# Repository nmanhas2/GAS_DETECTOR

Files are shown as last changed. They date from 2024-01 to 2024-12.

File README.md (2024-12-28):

# GAS_DETECTOR
Gas Detection project I made while attending NAIT

This includes the PCB and circuit design I made using KiCad EDA. 

Here's how it works:

-Using a gas sensor to detect smoke/gas in PPM (parts per million, standard for measuring the volume of a gas)

-Once the sensor detects a certain amount of gas (displayed on an I2C supported LCD), an “alarm” activates (piezo buzzer). The volume of gas is not accurate I believe, as I had problems with determining the calculations

-The LCD will display the current volume of gas detected by the gas sensor in PPM

-Push button for Reset

Involves the following components:

-MQ-2 gas sensor, widely used with lots of resources/examples to look at, works at 5V (https://components101.com/sensors/mq2-gas-sensor) https://media.digikey.com/pdf/Data%20Sheets/Seeed%20Technology/101020055_Web.pdf

-LCD w/ I2C: AMC0802BR-B-Y6WFDY-I2C (https://www.digikey.ca/en/products/detail/orient-display/AMC0802BR-B-Y6WFDY-I2C/12089323), cheap on digikey, runs at 5V as well. 0111110 = I2C address 

-BH9VPC 9V battery holder (had this on hand) + LM7805 linear voltage regulator to get the 5V needed for everything

-ATmega328P for the microcontroller https://ww1.microchip.com/downloads/en/DeviceDoc/Atmel-7810-Automotive-Microcontrollers-ATmega328P_Datasheet.pdf

-Piezo Buzzer for the alarm (PS1240P02BT) https://www.digikey.ca/en/products/detail/tdk-corporation/PS1240P02BT/935924, can run on 3V minimum up to a maximum of 30Vp

-A push button

Here is the circuit schematic (may be difficult to see):



Here is the PCB design:





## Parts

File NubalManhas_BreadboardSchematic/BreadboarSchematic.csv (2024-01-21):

Source: | C:\Users\manha\OneDrive\Desktop\BreadboarSchematic\BreadboarSchematic.kicad_sch
Date: | 10/18/2022 11:07
Tool: | Eeschema (6.0.7)
Generator: | C:\Program Files\KiCad\6.0\bin\scripting\plugins/bom_csv_grouped_by_value_with_fp.py
Component Count: | 19
Ref | Qnty | Value | Cmp name | Footprint | Description | Vendor
BT1, | 1 | BH9VPC | BH9VPC | MyLib:BAT_BH9VPC
C1, C2, | 2 | 100uF | C_Polarized | Capacitor_SMD:CP_Elec_6.3x5.8 | Polarized capacitor
C3, C4, | 2 | 18pF | C | Capacitor_SMD:C_1206_3216Metric | Unpolarized capacitor
J1, | 1 | AVR-ISP-MK2 | Conn_02x05_Odd_Even | Connector_PinSocket_2.54mm:PinSocket_2x05_P2.54mm_Vertical | Generic connector, double row, 02x05, odd/even pin numbering scheme (row 1 odd numbers, row 2 even numbers), script generated (kicad-library-utils/schlib/autogen/connector/)
J2, | 1 | SKU 101020055 | Conn_01x04 | Connector_PinHeader_2.54mm:PinHeader_1x04_P2.54mm_Vertical | Generic connector, single row, 01x04, script generated (kicad-library-utils/schlib/autogen/connector/)
J3, | 1 | AMC0802BR-B-Y6WFDY-I2C | Conn_02x05_Odd_Even | Connector_PinHeader_2.54mm:PinHeader_2x05_P2.54mm_Vertical | Generic connector, double row, 02x05, odd/even pin numbering scheme (row 1 odd numbers, row 2 even numbers), script generated (kicad-library-utils/schlib/autogen/connector/)
LS1, | 1 | PS1240P02BT | PS1240P02BT | MyLib:XDCR_PS1240P02BT
Q1, | 1 | MMBT3904 | MMBT3904 | Package_TO_SOT_SMD:SOT-23 | 0.2A Ic, 40V Vce, Small Signal NPN Transistor, SOT-23
R1, | 1 | 10k | R_US | Resistor_SMD:R_1206_3216Metric | Resistor, US symbol
R2, | 1 | 1k | R_US | Resistor_SMD:R_1206_3216Metric | Resistor, US symbol
R3, | 1 | 82k | R_US | Resistor_SMD:R_1206_3216Metric | Resistor, US symbol
R4, R5, | 2 | 4.7k | R_US | Resistor_SMD:R_1206_3216Metric | Resistor, US symbol
RV1, | 1 | 10k | R_Potentiometer | Potentiometer_THT:Potentiometer_Bourns_3296W_Vertical | Potentiometer
U1, | 1 | LM7805_TO220 | LM7805_TO220 | Package_TO_SOT_THT:TO-220-3_Vertical | Positive 1A 35V Linear Regulator, Fixed Output 5V, TO-220
U2, | 1 | ATmega328P-P | ATmega328PB-A | Package_QFP:TQFP-32_7x7mm_P0.8mm | 20MHz, 32kB Flash, 2kB SRAM, 1kB EEPROM, TQFP-32
Y1, | 1 | HC49-4H 16MHz | Crystal | Crystal:Crystal_SMD_ECS_CSM3X-2Pin_7.6x4.1mm | Two pin crystal
 | 4 | M3x15+6mm Nylon Hex Male to Female Standoff
 | 4 | M3x15mm Double Female Standoff
SW1, | 1 | 108-0047-evx | SW_SPST | SamacSys_Parts:1080047EVX | Single Pole Single Throw (SPST) switch
D1, | 1 | /SML-LX1206SRW-TR | LED | BH9VPC:RESC3015X65 | Light emitting diode

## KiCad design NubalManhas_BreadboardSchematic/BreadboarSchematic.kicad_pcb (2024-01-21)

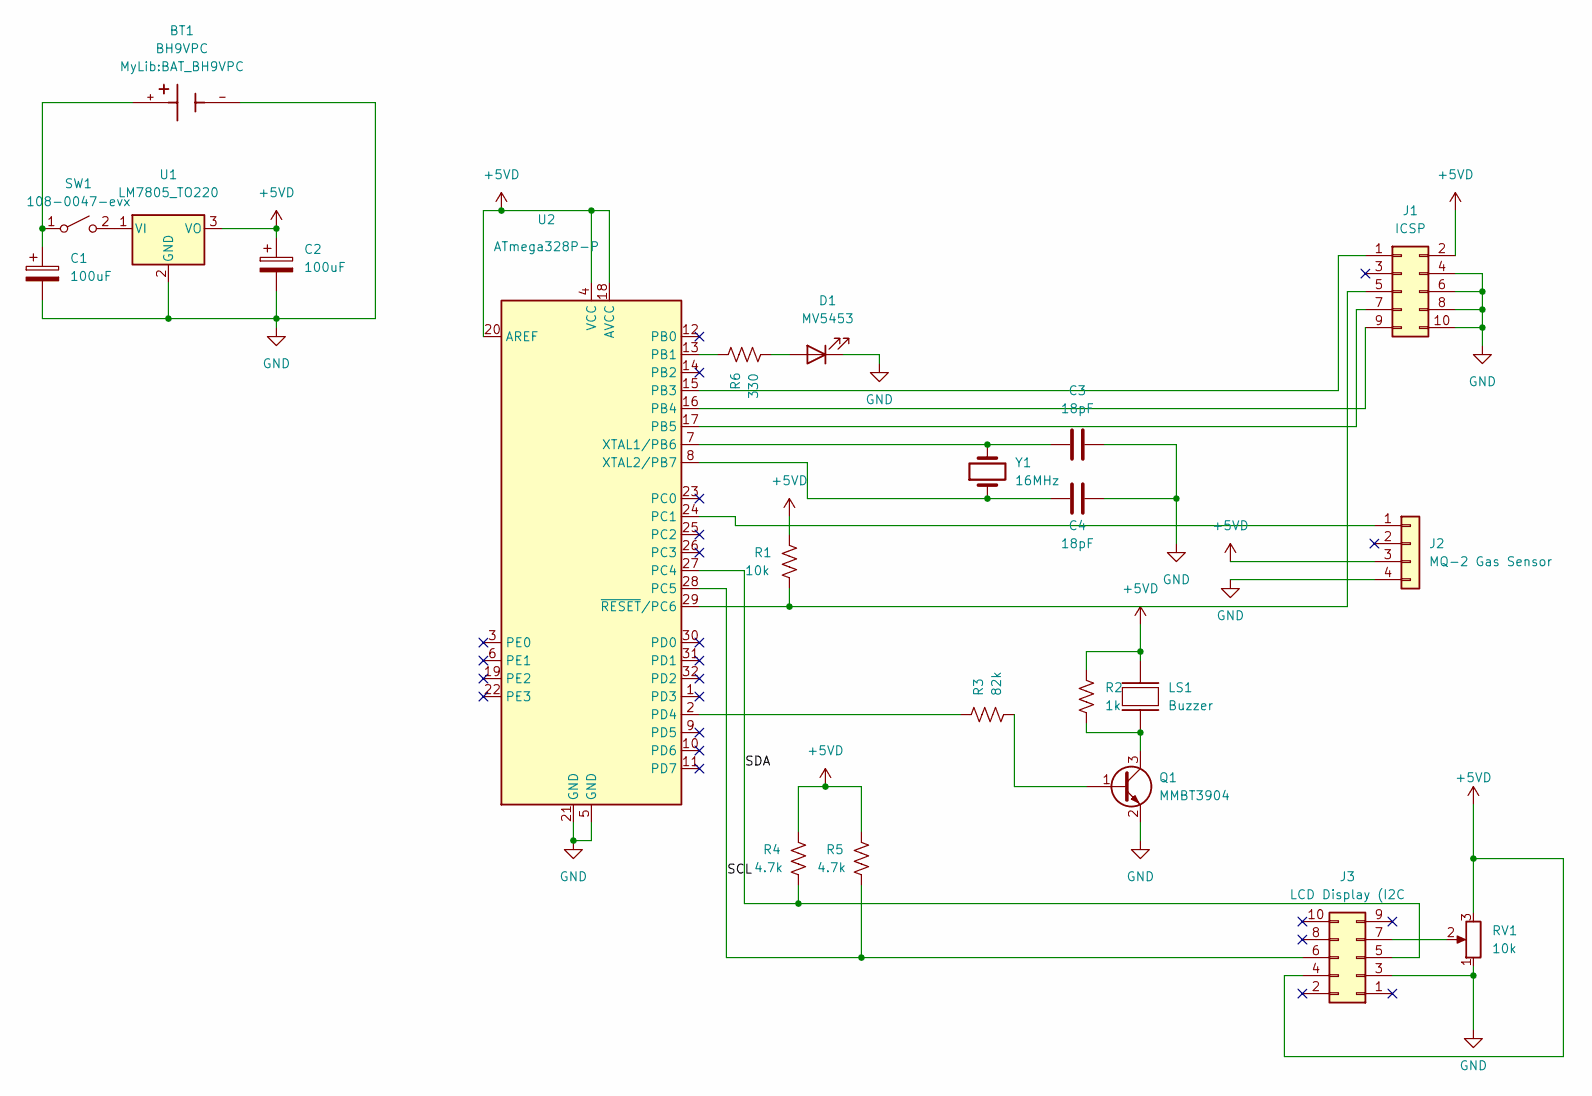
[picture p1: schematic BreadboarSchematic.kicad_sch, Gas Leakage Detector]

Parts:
BT1: BH9VPC; BAT_BH9VPC; PARTREV F
C1, C2: 100uF; CP_Elec_6.3x5.8
C3, C4: 18pF; C_1206_3216Metric
D1: MV5453; RESC3015X65
J1: ICSP; PinSocket_2x05_P2.54mm_Vertical
J2: MQ-2 Gas Sensor; PinHeader_1x04_P2.54mm_Vertical
J3: LCD Display (I2C; PinHeader_2x05_P2.54mm_Vertical
LS1: Buzzer; XDCR_PS1240P02BT
Q1: MMBT3904; SOT-23
R1: 10k; R_1206_3216Metric
R2: 1k; R_1206_3216Metric
R3: 82k; R_1206_3216Metric
R4, R5: 4.7k; R_1206_3216Metric
R6: 330; R_1206_3216Metric
RV1: 10k; Potentiometer_Bourns_3296W_Vertical
SW1: 108-0047-evx; 1080047EVX
U1: LM7805_TO220; TO-220-3_Vertical
U2: ATmega328P-P; TQFP-32_7x7mm_P0.8mm
Y1: 16MHz; Crystal_SMD_ECS_CSM3X-2Pin_7.6x4.1mm

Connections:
+5VD: C2.1, J1.2, J2.3, J3.4, LS1.2, R1.1, R2.1, R4.1, R5.1, RV1.3, U1.3 (VO), U2.4 (VCC), U2.18 (AVCC), U2.20 (AREF)
/SCL: J3.6, R5.2, U2.28 (PC5)
/SDA: J3.5, R4.2, U2.27 (PC4)
GND: BT1.-, C1.2, C2.2, C3.2, C4.2, D1.1 (K), J1.4, J1.6, J1.8, J1.10, J2.4, J3.3, Q1.2 (E), RV1.1, U1.2 (GND), U2.5 (GND), U2.21 (GND)
unnamed: BT1.+, C1.1, SW1.1 (A)
unnamed: C3.1, U2.7 (XTAL1/PB6), Y1.2
unnamed: C4.1, U2.8 (XTAL2/PB7), Y1.1
unnamed: D1.2 (A), R6.2
unnamed: J1.1, U2.15 (PB3)
unnamed: J1.5, R1.2, U2.29 (~RESET/PC6)
unnamed: J1.7, U2.17 (PB5)
unnamed: J1.9, U2.16 (PB4)
unnamed: J2.1, U2.24 (PC1)
unnamed: J3.7, RV1.2
unnamed: LS1.1, Q1.3 (C), R2.2
unnamed: Q1.1 (B), R3.2
unnamed: R3.1, U2.2 (PD4)
unnamed: R6.1, U2.13 (PB1)
unnamed: SW1.2 (B), U1.1 (VI)

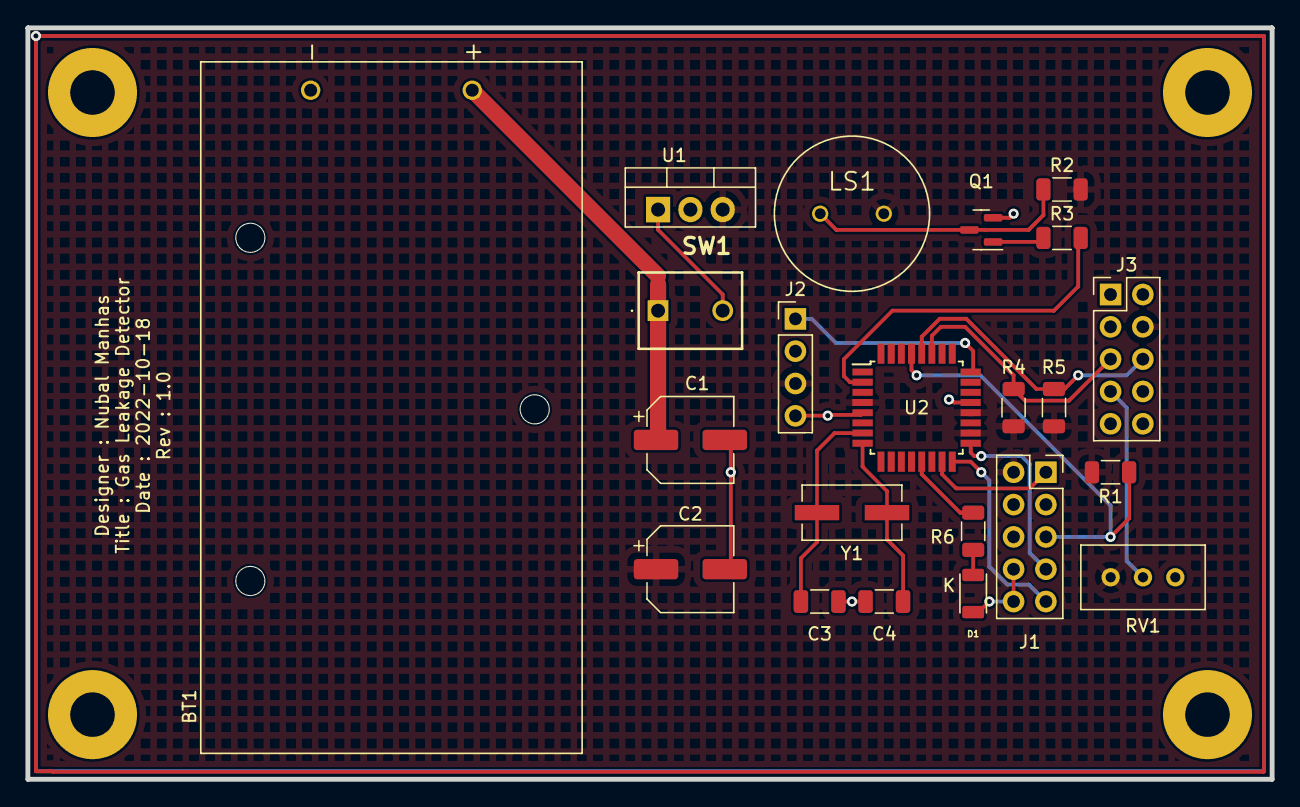
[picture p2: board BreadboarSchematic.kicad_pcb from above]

Board: 2 copper layers, 97.8 x 59.1 mm, 22 parts (0 on the bottom side), 19 nets.

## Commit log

2024-01-20 Uploaded KiCad Design
    [BreadboarSchematic.kicad_pcb, BreadboarSchematic.kicad_sch]
2024-01-21 Added KiCad design
    [BreadboarSchematic-B_Cu.gbr, BreadboarSchematic-B_Mask.gbr, BreadboarSchematic-B_Paste.gbr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]
